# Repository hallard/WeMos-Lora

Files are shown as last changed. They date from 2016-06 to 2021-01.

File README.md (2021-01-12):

# ESP8266 WeMos Shield for HopeRF RFM95 RFM96 RFM98 Lora Modules

This shield is used to hold HopeRF [Lora module][4] Software with WeMos ESP8266 boards it has just few minimal features. 
- I2C Pullups placement
- Classic I2C 128x64 OLED connector
- Placement for RFM95/96/98 Lora module
- Placement for choosing single Wire, SMA or u-FL Antenna type 
- 2 x WS2812B Type LED for visual indication
- Custom switch on GPIO2
- Added footprint for Microchip 24AA02E64 64 bits serial number (v1.1+) 
- Added Solder PAD jumper to be able to connect GPIO16 to Reset to enable deep sleep (V1.2+)

You can find more information on WeMos D1 mini boards ([mini][1], [mini pro][7], [mini lite][8]), it's really well documented.
I now use WeMos boards instead of NodeMCU's one because they're just smaller, features remains the same, but I also suspect WeMos regulator far better quality than the one used on NodeMCU that are just fake of originals AMS117 3V3.

Boards arrived, I tested them, works fine with forked version of [single Channel LoRaWAN Gateway][5] but you can use any program that is compatible with RFM95 Lora module according it to real pinout.

## Detailed Description

Look at the schematics for more informations.

SPI connexion is classic (MOSI/MISO/CLK), 

**New v1.3** Solder pad on bottom layer to be able to switch 3V3 and GND Pin. It's configured as old version mapping by default (silkscreen is correct). 

Since V1.2, chip Select is still connected with GPIO16 by default but solder pad on bottom of the board allow you to connect GPIO16 to RESET for Deep Sleep. In this case: 

- add and solder R3 Pulldown (100K) to make RFM95 SPI device always selected
- on bottom solder pad cut trace between GPIO19 and SEL 
- on bottom solder join GPIO16 and RST with solder

Other pins that may need be adapted into code (for example if you use TTN network gateway code) according to the following pinout

Please not that to avoid 3 GPIOs for DIO0,DIO1,DIO2 Interrupt, these 3 are OR'ed with 3 diodes, respectively named D2,D3 and D4. This permit to use only one IRQ pin (here GPIO15). This is only possible because on IRQ routine the RFM9x IRQ register is read and then software knows which one has been triggered.
You can see more details ont this dedicated LMIC [Pull Request][6]

```
   WeMos D1          RFM9x Module
  GPIO12 (D6) <----> MISO
  GPIO13 (D7) <----> MOSI
  GPIO14 (D5) <----> CLK
  GPIO15 (D8) <----> DIO0/D2 OR DIO1/D3 OR DIO2/D4
  GPIO16 (D0) <----> SEL Chip Select (depending on bottom solder PAD position)

   WeMos D1         Shield Feature
  GPIO5  (D1) <----> I2C SCL
  GPIO4  (D2) <----> I2C SDA
  GPIO0  (D3) <----> WS2812 LEDS
  GPIO2  (D4) <----> Push Button
  GPIO16 (D0) <----> RESET (depending on bottom solder PAD position)
```

## Schematic  

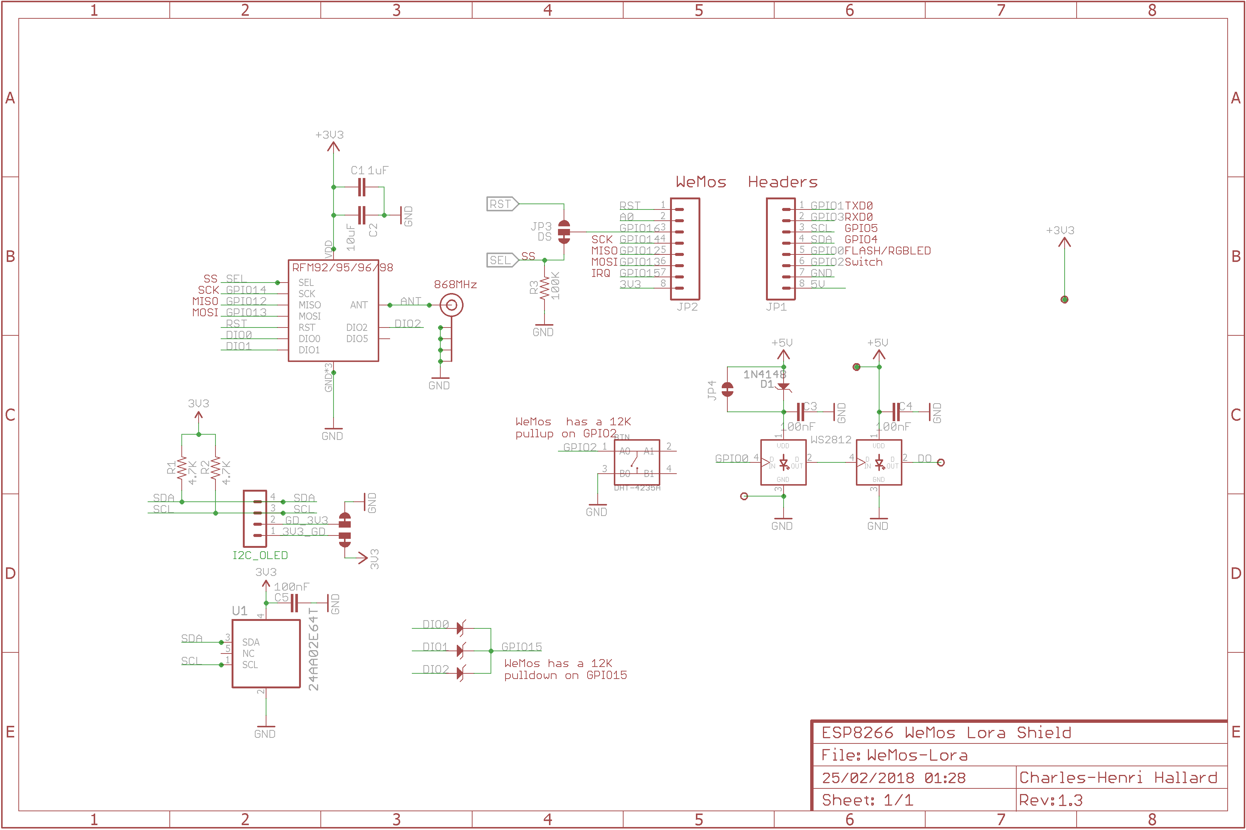
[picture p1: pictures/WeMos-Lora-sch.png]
schematic
  

## Bill Of Material

Nothing fancy, all components are 0805 and/or PTH and can be ordered almost anywhere (digikey, mouser, radiospare, ...). 
use only what you need dependings on what you want to do. You can find lot of components on ebay or aliexpress, but since vendors are often ephemere, I put for reference the BOM on well known providers.

Here is the [octopart BOM](https://octopart.com/bom-tool/SJPhS5Am)

## Firmware  

[firmware](https://github.com/hallard/WeMos-Lora/tree/master/firmware)  

## Boards  

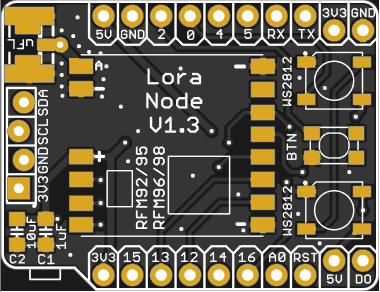
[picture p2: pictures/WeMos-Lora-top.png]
&nbsp;
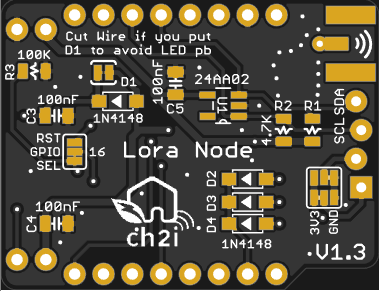
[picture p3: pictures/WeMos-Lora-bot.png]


~~You can order the PCB of this board at [PCBs.io][3] if you do so, PCBs.io give me discount that allow me to buy some new created boards.~~
   
Looks like PCBs.io is gone, I do not have any rewards from PCBs.io since August 2020 and my free order placed after are still not received, so my guess they are not on business anymore.

So you can order the board on [oshpark](https://oshpark.com/shared_projects/E9P1U0Ae). It's a pitty after several discuss with OSHPark that I can't have any rewards for each people ordering my boards, this would allow me to order free PCB for shared projects and create new ones. For information my shared boards generated a total of **$285 162.00** orders at PCBs.io in 4 years, not bad at all :-)

Hoping one day OSHparks will thanks me giving them this market. 

## Assembled boards (V1.0)

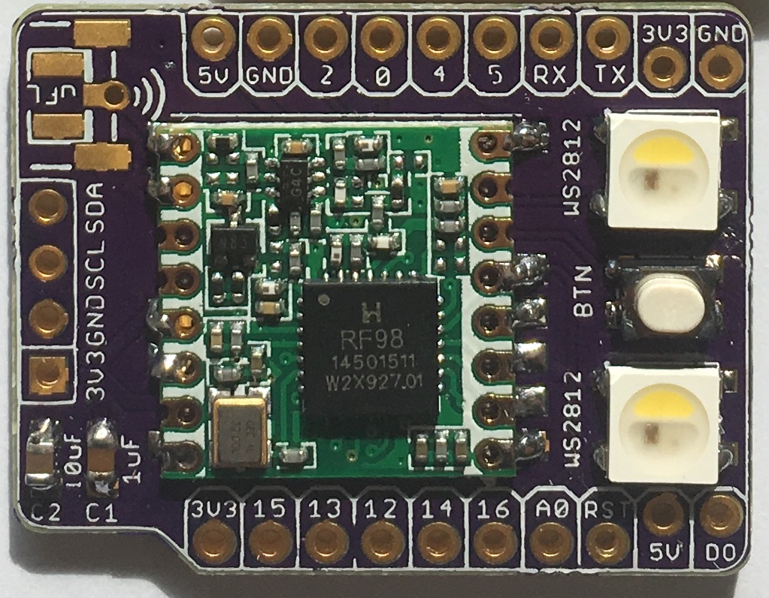
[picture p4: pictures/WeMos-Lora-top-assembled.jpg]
    
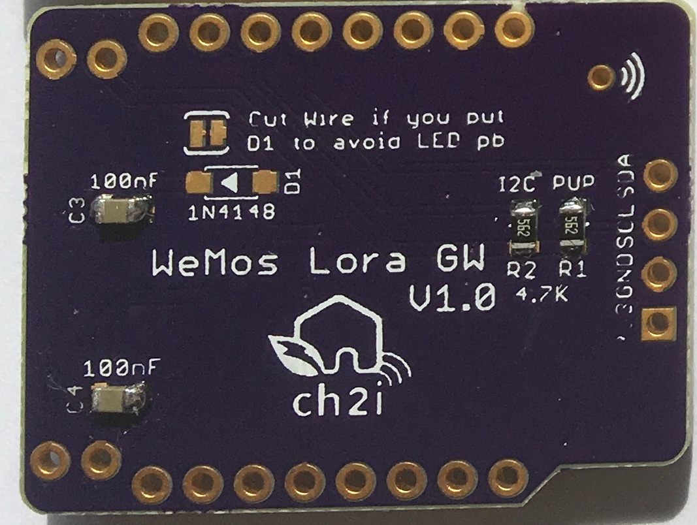
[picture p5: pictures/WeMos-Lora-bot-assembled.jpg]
    

## License

   

This work is licensed under a [Creative Commons Attribution-NonCommercial 4.0 International License](http://creativecommons.org/licenses/by-nc/4.0/)    
If you want to do commercial stuff with this project, please contact [CH2i company](https://www.ch2i.eu/en#support) so we can organize an simple agreement.

# Misc

See news and other projects on my [blog][2] 
 
[1]: https://wiki.wemos.cc/products:d1:d1_mini
[2]: https://hallard.me
[3]: https://PCBs.io/share/4Q1Z4 
[4]: http://www.hoperf.com/rf_transceiver/lora/
[5]: https://github.com/hallard/ESP-1ch-Gateway/
[6]: https://github.com/matthijskooijman/arduino-lmic/pull/34
[7]: https://wiki.wemos.cc/products:d1:d1_mini_pro
[8]: https://wiki.wemos.cc/products:d1:d1_mini_lite

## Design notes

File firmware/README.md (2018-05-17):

Lora Firmware for ESP8266 or ESP32 with RFM95
=============================================

You can use this [firmware fork](https://github.com/SensorsIot/ESP-1ch-Gateway) for example as Single Chanel Gateway

Dependencies
------------
- Arduino [ESP8266][6]
- @me-no-dev [ESPAsyncWebServer][4] library
- @me-no-dev [ESPAsyncTCP][5] library 
- [nodejs][7] for web pages development test 

Misc
----
See news and other projects on my [blog][2] 
 
[1]: http://www.wemos.cc/
[2]: https://hallard.me
[3]: http://terminal.jcubic.pl/
[4]: https://github.com/me-no-dev/ESPAsyncWebServer
[5]: https://github.com/me-no-dev/ESPAsyncTCP
[6]: https://github.com/esp8266/Arduino/blob/master/README.md
[7]: https://nodejs.org/
[8]: https://github.com/hallard/WeMos-RN2483/blob/master/README.md
[9]: http://cdn.rawgit.com/hallard/WebSocketToSerial/master/webdev/index.htm
[10]: https://github.com/hallard/WebSocketToSerial/tree/master/webdev
[11]: https://github.com/hallard/WebSocketToSerial/blob/master/webdev/create_spiffs.js
[12]: https://github.com/hallard/WebSocketToSerial/blob/master/webdev/web_server.js
[13]: https://github.com/hallard/WebSocketToSerial/tree/master/data

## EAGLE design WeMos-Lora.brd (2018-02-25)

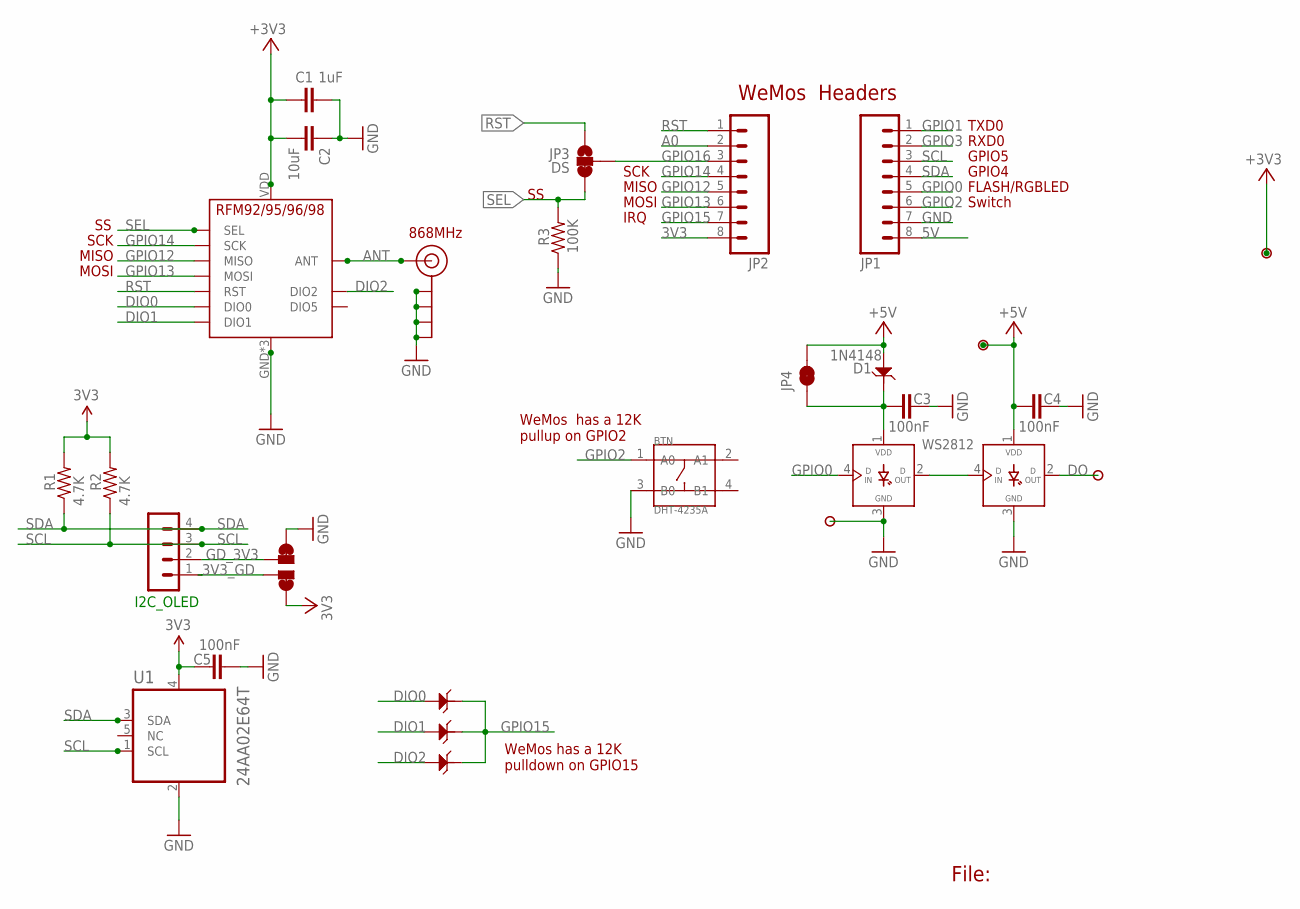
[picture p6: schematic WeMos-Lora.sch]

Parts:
BTN: DHT-4235A; SW4-SMD-4.2X3.2X2.5MM
C1: 1uF; 0805-CAP-LARGEPADS
C2: 10uF; 0805-CAP-LARGEPADS
C3, C4, C5: 100nF; 0805-CAP
D1, D2, D3, D4: 1N4148; SOD123-2.7X1.6
I2C_OLED: CON_HEADER_1X04'LOCK'; 1X04_LOCK
J$2: ANTENNATINY; SMA_UFL_PAD_TINY
JP1, JP2: M08NO_SILK_FEMALE_PTH; 1X08_NO_SILK
JP3: DS; PAD-JUMPER-3-2OF3_NC_BY_TRACE_YES_SILK_FULL_BOX
JP4: JUMPER-PAD-2-NC_BY_TRACE; PAD-JUMPER-2-NC_BY_TRACE_YES_SILK
P1, P2, P3, P4: PADNORMAL; PAD
R1, R2: 4.7K; 0805-RES
R3: 100K; 0805-RES
U1: 24AA02E64T; SOT95P270X145-5N
U$2: PAD-JUMPER-SWAPSWAP; PAD-JUMPER-SWAP
U$5: RFM95
WS1, WS2812: WS2812B

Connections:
3V3: C1.2, C2.2, C5.1, JP2.8, P4.1, R1.2, R2.2, U1.4 (VCC), U$2.4, U$2.44 (4), U$5.VDD (VCC)
3V3_GD: I2C_OLED.1, U$2.3
5V: C4.1, D1.1, JP1.8, JP4.2, P1.1, WS1.1 (VDD)
A0: JP2.2
ANT: J$2.ANT1 (SIGNAL), J$2.ANT2 (SIGNAL), J$2.ANT3 (SIGNAL), U$5.ANT
DIO0: D2.1, U$5.DIO0
DIO1: D3.1, U$5.DIO1
DIO2: D4.1, U$5.DIO2
DO: P2.1, WS1.2 (DOUT)
GD_3V3: I2C_OLED.2, U$2.2
GND: BTN.3 (B0), C1.1, C2.1, C3.2, C4.2, C5.2, J$2.GND1 (GND), J$2.GND2 (GND), J$2.GND3 (GND), J$2.GND4 (GND), JP1.7, P3.1, R3.1, U1.2 (VSS), U$2.1, U$2.11 (1), U$5.GND, U$5.GND1 (GND), U$5.GND2 (GND), WS1.3 (GND), WS2812.3 (GND)
GPIO0: JP1.5, WS2812.4 (DIN)
GPIO1: JP1.1
GPIO2: BTN.1 (A0), JP1.6
GPIO3: JP1.2
GPIO12: JP2.5, U$5.MISO
GPIO13: JP2.6, U$5.MOSI
GPIO14: JP2.4, U$5.SCK
GPIO15: D2.2, D3.2, D4.2, JP2.7
GPIO16: JP2.3, JP3.2
unnamed: WS1.4 (DIN), WS2812.2 (DOUT)
RST: JP2.1, JP3.1, U$5.RST
SCL: I2C_OLED.3, JP1.3, R2.1, U1.1 (SCL)
SDA: I2C_OLED.4, JP1.4, R1.1, U1.3 (SDA)
SEL: JP3.3, R3.2, U$5.NSS (SEL)
VLED: C3.1, D1.2, JP4.1, WS2812.1 (VDD)

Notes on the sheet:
File:
FLASH/RGBLED
MISO
GPIO4
GPIO5
RXD0
TXD0
MOSI
SCK
IRQ
WeMos Headers
868MHz
Switch
WeMos has a 12K pullup on GPIO2
WeMos has a 12K pulldown on GPIO15

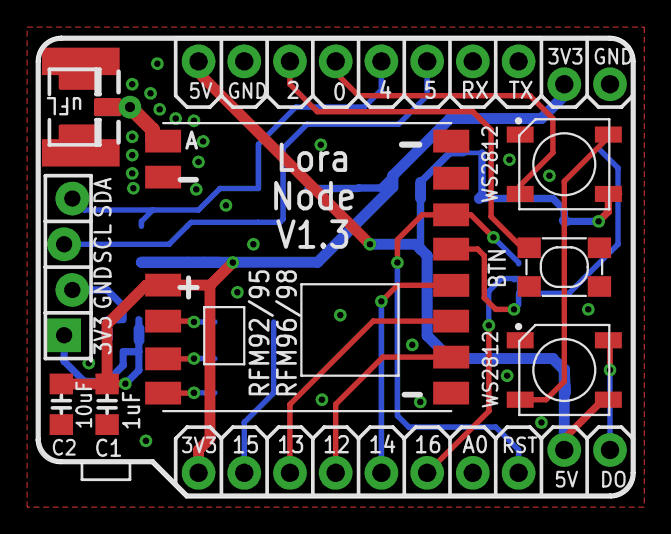
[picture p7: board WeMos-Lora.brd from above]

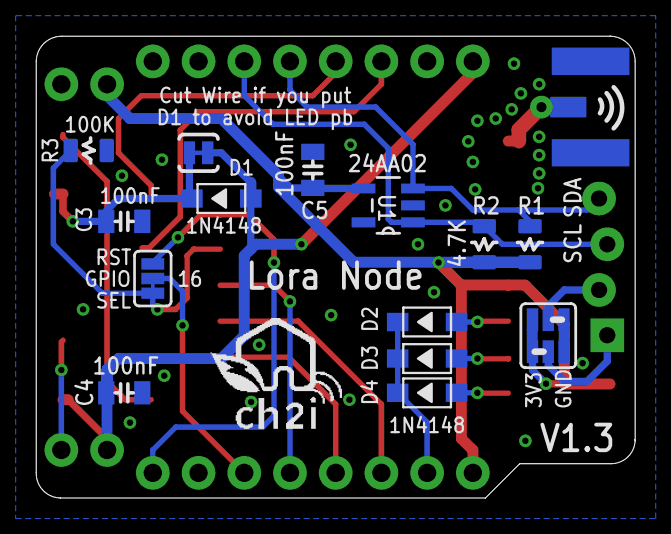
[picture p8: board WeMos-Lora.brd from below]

Board: 2 copper layers, 33.3 x 25.7 mm, 29 parts (15 on the bottom side), 23 nets.

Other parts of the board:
U$4: LOGO_CH2I_75MM

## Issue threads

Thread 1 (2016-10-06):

Replace 24AA02E64

Vitaliy86, 2016-10-06:
I cannot find 24AA02E64 for buy, can i replace it?

hallard, 2016-10-17:
@Vitaliy86
If you don't have the according code in your firmware, you can skip this chip, it's just in case you need specific unique ID on board and don't want to put in in the code.
you can find it on lot of electronic component provider such as
-  [digikey](http://www.digikey.com/product-detail/en/microchip-technology/24AA02E64-I-SN/24AA02E64-I-SN-ND/3908643)
- [mouser](http://www.mouser.fr/ProductDetail/Microchip-Technology/24AA02E64-I-SN)
- [TME](http://www.tme.eu/gb/details/24aa02e64-i_sn/serial-eeprom-memories-integ-circ/microchip-technology/#)

Closed 2016-10-22.

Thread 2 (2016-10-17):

SSD1306 Header Alignment

tkerby, 2016-10-17:
Hi

In the 1.1 version the pins for the display on the board edge are out of alignment. The png image you have of the board in the repository also reflects this.

Thanks

Tim

hallard, 2016-10-17:
@tkerby
The pin for the display are not aligned to be able to plug display without soldering it for testing or to let the header connector in place when soldering it, it's called "header lock" and used very often by sparkfun and other ;-)

Closed 2016-10-17.

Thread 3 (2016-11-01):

Unable to use deep sleep

JaapBraam, 2016-11-01:
I am running a LMIC implementation using this shield. This works fine, but the choice of using GPIO16 for SS breaks the possibility to use the timed deep sleep feature of the ESP8266. In order to make timed deep sleep work you have to connect GPIO16 to the ESP's RST pin. When using this shield, the board won't start up properly when connecting GPIO16 to RST. Maybe, in the next version, the GPIO16 pin can be used for an optional feature so there will be a way to use timed deep sleep.
Especially for battery powered LoraWan nodes a lot of power can be preserved by using deep sleep.

tkerby, 2016-11-24:
I've come across exactly the same issue here. I'd be tempted to wire the button to D0/GPIO16 instead. With a solder bridge option, you can either have deep sleep or a button input. If you select deep sleep then the button becomes an external reset that should cause the deep sleep to end early.

The other option here with the existing boards would be an external watchdog timer IC. The ESP would go into deep sleep then the watchdog would wake it up some time later.  To save pins, the SS line would suffice as a watchdog reset - ie any radio activity keeps the watchdog odd until deep sleep is issued

kragupat, 2016-12-02:
@JaapBraam  @tkerby
Which LMIC stack are you guys running with this board, I havent had much luck with either of the 2 below
https://github.com/hallard/arduino-lmic
https://github.com/matthijskooijman/arduino-lmic

any help is appreciated.

TheNitek, 2017-04-05:
I just create a fork ( https://github.com/TheNitek/WeMos-Lora ) which removes the LEDs and the button and also frees GPIO16. I just order my board, so I'm not sure yet everything still works, but maybe you want to give it a shot.

hallard, 2017-08-03:
Just released V1.2, if you want to try deep sleep, new PCB revision allow it ;-)

Closed 2017-08-03.

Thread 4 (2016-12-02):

Does 1.1 version work?

kragupat, 2016-12-02:
Hi ,
I recently ordered the board from pcbs.io  but so far haven't been able to get it working.
Tried it with your LMIC fork version both with and with out the diodes.
Has any one been able to successfully run it with 1.1 version boards.
Wemos keeps crashing right after serial.begin.
Also with the sheild attached I cant upload updated skeptch any more from arduino IDE, works ok if I take out the shield.

Thanks

hallard, 2018-02-25:
Did you solved your problem?
Version 1.2 works fine. I think I've got old V1.1 working version somewhere.

Closed 2018-02-25.

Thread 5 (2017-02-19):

DIO 1/2/3 and Diode 1n4148 - on schematics you have 3 diodes and on assebled picture only one

Netoperz, 2017-02-19:
As in title, the design and assembled dev pictures are different, could you tel me why, and if i want to connect the RFM95 module i should use 3 diodes as i understand, according to the schematics.

SensorsIot, 2017-04-20:
Same question for me. I had to remove the diode to DIO2, because it was always high and the gateway did not work. I also do not understand the role of D1. Is it necessary?
And in my case, the WiFi Neopixel shines red, even if the Gateway works properly.

hallard, 2017-08-03:
Guys
D1 is to lower power of WS2812B to 4.3V like this DI line in drived with 3.3V works, but it's not mandatory, new leds can be drived with 3.3V input when powered at 5V, you just need to try in fact.

To be full LMIC compliant (in term of node) I or'ed DIO0/DIO1/DIO2 with D2/D3/D4 on V1.1 version. May me for GW as said @SensorsIot we need to remove it depending on Server code (management of DIO)

Closed 2017-08-03.

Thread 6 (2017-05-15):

Please create shield for NiceRF Lora1276 with sensitivity up to -139 dBm

JosefJezek, 2017-05-15:
- https://www.aliexpress.com/item/2pcs-4km-range-Lora-TM100mW-SX1276-SPI-interface-Sensitivity-139-dBm-433MHz-LoRa1276-rf-long-distance/2015211844.html
- http://www.nicerf.com/product_146_136.html

JosefJezek, 2017-05-16:
RFM95W has sensitivity	-123dBm :-/

https://www.digikey.co.nz/product-detail/en/rf-solutions/RFM95W-868S2/RFM95W-868S2-ND/5051755

JosefJezek, 2017-05-16:
RN2483 has output power only 14 dBm

@hallard FYI

hallard, 2017-06-08:
@JosefJezek yes it could be cool but I'm pretty short in time for now and the footprint for this device does not exist for my PCB software Eagle CAD.
If you find an eagle library for it I can take some time to create it.

Closed 2017-08-03.

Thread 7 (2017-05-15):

Multiplexing made easier

platenspeler, 2017-05-15:
Hi,

I have been implementing the dio0,dio1,dio2 pin multiplexing in my single channel gateway using your excellent PCB.

When doing the same in regular LoRa node using your code I just wondered why you do not use the lmic_pin list. If dio[0]==dio[1] one would assume that you are multplexing the pins for a ESP8266 which will make the code really simple.

Maarten

PS. Something like

> static void hal_io_check() {
    uint8_t i;
  // If two DIO pins are equal, we assume pin multiplexing
  if (lmic_pins.dio[0]==lmic_pins.dio[1])
  {
	// Check IRQ flags in radio module
	if ( radio_has_irq() )
		radio_irq_handler(0);
  }
  //
  else {
    for (i = 0; i < NUM_DIO; ++i) {
        if (lmic_pins.dio[i] == LMIC_UNUSED_PIN)
            continue;

        if (dio_states[i] != digitalRead(lmic_pins.dio[i])) {
            dio_states[i] = !dio_states[i];
            if (dio_states[i])
                radio_irq_handler(i);
        }
    }
  }
}

hallard, 2017-05-23:
@platenspeler
Not sure to understand, you are multiplexing DIO pins with diode, and all DIO are so going to only one IO correct ?
If so you just have to check only one pin (the others are set to LMIC_UNUSED_PIN) and the LMIC should works right out of the box without any code modification.

Another possibility is to not connect any GPIO pin and check IRQ register of RFM95 module, the fork to support this No DIO connexion is [here](https://github.com/hallard/arduino-lmic) and works fine on all my nodes ;-)

Closed 2017-08-03.

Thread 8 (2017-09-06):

lolin?

xor256, 2017-09-06:
meybe using https://www.banggood.com/Wemos-Lolin-ESP32-OLED-Module-For-Arduino-ESP32-OLED-WiFi-Bluetooth-Dual-ESP-32-ESP-32S-ESP8266-p-1148119.html
esp + oled

what You thing about cc1101
3 band

hallard, 2018-02-25:
Something like this maybe ? Sorry long time ago
https://github.com/hallard/LoLin32-Lora

Closed 2018-02-25.

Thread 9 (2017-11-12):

Can't find the right SMA connector to fiit this pcb

certeza, 2017-11-12:
The placement of the center pin seems unusual.
Where can I find the right SMA connector?

marssystems, 2017-11-12:
These SMA connectors work perfectly for me -

https://www.ebay.co.uk/itm/5pcs-End-Launch-PCB-Mount-Bulkhead-SMA-Female-RF-Coaxial-Connector-Straight-I6V4/282493230059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

certeza, 2017-11-12:
Thnx!

Closed 2018-02-25.

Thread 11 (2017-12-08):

Screen Print Error?

KevDuino, 2017-12-08:
Thanks for this great board.
I made some problems for myself following the screen print.  The board matches the circuit diagram with NSS connected to GPIO16.  The Detail Description is also clear.  I think RST and SEL are labelled incorrectly.

hallard, 2018-02-25:
Correct, fixed in V1.3, thanks for pointing out

Closed 2018-02-25.

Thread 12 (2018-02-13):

OLED module PINs

DooMMasteR, 2018-02-13:
The order seems a bit weird, 99% of the cheap modules have the pin in the order

```GND Vcc SCL SDA```

and not

```Vcc GND SCL SDA```

as on the your PCB

hallard, 2018-02-24:
You're right, but when I created the board 90% of OLED was in this order, after that we had OLED price going up then again down, and I saw they have switched the pin, don't know why they do that but was not a good idea ;-)
that's why on new boards I make you can revert vcc/gnd by solder pad, I need to update this one

hallard, 2018-02-25:
Fixed in V1.3

Closed 2018-02-25.

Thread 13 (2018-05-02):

Button on ebay

incyi, 2018-05-02:
Hi,

Can you help me to find the button on ebay ? I can't find it. I found this one:
https://www.ebay.com/itm/100pcs-3X6X2-5mm-Tactile-Push-Button-Switch-Tact-Switch-Micro-Switch-2Pin-SMD-S2/261995936109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

KevDuino, 2018-05-02:
I used:
 https://www.aliexpress.com/item/20PCS-LOT-SMD-3-4-2-0MM-touch-switch-button-switch-feet-of-copper-legs-3X4X2/32774579893.html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
Aliexpress, 20PCS/LOT SMD 3 * 4 * 2.0MM touch switch button switch feet of copper legs 3X4X2.0MM SMD 4P 3X4X2 4Pin, £0.74 including delivery.

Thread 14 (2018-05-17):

Bill of materials

jpmeijers, 2018-05-17:
Please add a list of components needed to populate this board. I was unaware that I needed 3 diodes to get it in a usable state. I am also still unsure which exact component the diodes should be. Are they 0805?

* Number (ex. D1, R3)
* Value (ex. 1N4148, 10K)
* Footprint/size (ex. 0805)
* A link to a source for the component

hallard, 2018-05-17:
@jpmeijers
As indicated in the readme, diodes are not mandatory is you use my LMIC fork.
If not, then you need to solder them. Since schematics and board files are in the repo I thought it was easy to find these informations about components. But I was wrong, sorry.

So here is the [octopart BOM](https://octopart.com/bom-tool/SJPhS5Am) file, I've updated to ReadMe to add this link

Thanks for pointing it out.

Closed 2018-05-17.

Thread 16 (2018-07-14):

OLED Pins misalignment

hotzenklotz, 2018-07-14:
In v1.3 the holes for the OLED pins are misaligned. The center hole seems flipped and does not align perfectly with the other two PINs. This makes it hard to just "plug and play" a standard breadboard-friendly OLED screen.

Is there any reason for this layout?

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

hallard, 2018-09-17:
It's for soldering connector, like that it fit in place when soldering.
BTW you can also just plug OLED onto, it will also stay in place with this format.

hotzenklotz, 2018-09-17:
@hallard Which connector did you use?

I was hoping to plug [my 4 pin display](https://www.aliexpress.com/item/0-91-Inch-128x32-IIC-I2C-Blue-OLED-LCD-Display-DIY-Module-SSD1306-Driver-IC-DC/32793415973.html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) directly into the PCB.

Closed 2018-09-17.

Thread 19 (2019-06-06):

Pullup resistors on I2C, why?

atrent, 2019-06-06:
Hi, is there a motive for R1 and R2 (pullup resistors for SDA and SCL)?
I'd like to use Wemos pins D1 and D2 for a SoftwareSerial...
Thanks

pfeerick, 2019-06-29:
Because [I<sup>2</sup>C needs pullups](https://learn.sparkfun.com/tutorials/i2c/i2c-at-the-hardware-level).

If you're not going to use I<sup>2</sup>C, don't put them on.

atrent, 2019-07-10:
thanks for the reply (and sorry for the delay in my follow up)

I actually have an old version of the shield (see photo) and I've checked now that R1, R2 and the 24AA... chip are NOT present, so the fact that I could not activate a SoftwareSerial on those pins is to be investigated more, my bad

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

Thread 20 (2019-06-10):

SMD component list

leocopter, 2019-06-10:
Hi, could you provide the SMD component list ( with dimensions) ?
Thanks.

pfeerick, 2019-06-29:
Um... under Bill of Materials on the front readme?
> all components are 0805 and/or PTH

and

> Here is the [octopart BOM](https://octopart.com/bom-tool/SJPhS5Am)

leocopter, 2019-06-29:
Thank you.
Do you think this 24AA
02 :
https://m.ebay.ca/orderDetails?itemId=271542332935&txnId=2161023119017
Is the right one ?

Regards,

Chris

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

pfeerick, 2019-06-29:
Yeah, [that one](https://www.ebay.ca/itm/EEPROM-SERIAL-2KB-SMD-SOT-23-5-Part-24AA02T-I-OT/271542332935) looks like it should be fine... it's the right part number, and it's the five legger S0T-23-5, not the 8 leg SOIC-8 package.

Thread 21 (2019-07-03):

DIO0 GPIO15 boot fail

NitroProp, 2019-07-03:
Hi, i have an issue, the gateway works perfectly fine but i have a small problem, i have the gpio15 pulled down to ground with a 10k resistor, but if i connect the 1n4148 diode for dio0 on gpio15 the esp12e will not boot. If i leave the diode disconnected, power up the board and only then connect the diode on gpio15 it works like a charm, any idea about the reason ?

Thanks a lot

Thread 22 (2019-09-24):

BOM missing antenna connector

remrat, 2019-09-24:
Any advice on the type of antenna connector to put on the PCB?  I noticed the BOM is missing that info.

I would love to use a SMA or u.fl type antenna, but don't know of a connector that fits that footprint on the PCB.

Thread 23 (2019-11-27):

Older Versions

peterl3233, 2019-11-27:
I appear to have a quantity of older "Lora Node Mini" boards for Wemos D1 mini.  I bought them about 2 years ago. They do not have a version number or CH21 logo but have the number WS2812 screened just under the RFM9x moduls pads. The layout and parts placement is identical to V1.3 sans the extra features.
So, Question is:  Is this indeed an early version of WeMos-Lora and is is usable?
Thanks much Peter

TheNitek, 2019-11-27:
Is it maybe the early version of my fork (https://github.com/TheNitek/WeMos-Lora/)? I reduced the original in size an called it mini and reduced it further later on and started to call it micro.
If so it will still work perfectly fine.

TheNitek, 2019-11-27:
Looks like this: https://s3.amazonaws.com/pcbsio/svgs/43aeafab5f987c7c728c912dfaa8ddd3aa04478626dfc0893355db2fd9175ac8/top.svg

peterl3233, 2019-11-28:
Hi Claus; Its slightly different than both examples that you cited. This one has the OLED connector pins.  I found my records and I bought them from PCBS.io. Bought in September 2017. Searching their website no longer finds this one.  Hopefully you can see the attached photo.

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

TheNitek, 2019-11-28:
That’s my forked version

peterl3233, 2019-11-28:
Thanks much.  I just bought some RFM95's to play LoRa ... Too much fun!

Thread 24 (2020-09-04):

BOM missing diodes

gvtienen, 2020-09-04:
Hello,
Your BOM (at https://octopart.com/bom-tool/MsqCYjTr) is missing the 3 diodes

gvtienen, 2020-09-06:
Sorry, I was looking into the mini-LoRa BOM file :(

gvtienen, 2020-09-06:
Sorry, I was looking into the mini-LoRa BOM file :(

gvtienen, 2020-09-06:
Sorry, I was looking into the mini-LoRa BOM file :(

gvtienen, 2020-09-06:
Sorry, I was looking into the mini-LoRa BOM file :(

gvtienen, 2020-09-06:
Sorry never mind, I was mixing the mini-LoRa with the WeMos-Lora

gvtienen, 2020-09-06:
Sorry never mind, I was mixing the mini-LoRa with the WeMos-Lora

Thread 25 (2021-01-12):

Ordering new pcbs for WeMos Lora RFM9x Gateway Shield

saysphilippe, 2021-01-12:
Hi, I have tried several times to order your board from PCBs.io - but it looks like they have issues there. Are your boards available somewhere else?

hallard, 2021-01-12:
To be honest I do not have any rewards from PCBs.io since August 2020 so my guess they are not on business anymore because got boards never received

So I added link so you can order the board on [oshpark](https://oshpark.com/shared_projects/E9P1U0Ae)

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

saysphilippe, 2021-01-12:
Great, thank you!

henkiejan1, 2021-01-14:
First of all i do not work for TTGO or Lilygo. But i read that TTGO also made pcb's with a minimum quantity of 1. S[ee this from their website.](https://0.rc.xiniu.com/g3/M00/16/67/CgAH513o4-mAIb7uAAHywAhSKd0113.jpg) Maybe a good idea to contact TTGO?

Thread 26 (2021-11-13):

Correct Pins?

eboston, 2021-11-13:
I know this project is old, but it seems the hardware should still be usable.  I am trying to make a LoRa transmitter using the LoRa library in the Arduino IDE.  I am converting code I was running on a Heltec ESP32 LoRa board.  I am trying to follow this (https://github.com/SensorsIot/LoRa-Point-to-Point) which uses this board.  I'm not sure if the board has been assembled correctly, but I think it has.  Both the leds and oled are working, but I know they are not part of the LoRa portion.

In the sample code, it uses this command to configure the pins:
`  LoRa.setPins(16, 17, 15); // set CS, reset, IRQ pin`
It compiles and runs, but the receiver I have is not seeing anything.  They are both on the same frequency and SF.

Any suggestions on what might not be right?

EDIT:  I am seeing it get a package every once in awhile, so I guess it is transmitting, but most of the packets aren't being received.

Closed 2021-11-15.

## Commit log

2016-07-07 Version V1.1
    - OLED Display connector has now lock pad
    - Antenna signal with via all around
    - ground plane set to 12min blocking to avoid short circuit with
    connectors in rarely cases
    - Added footprint for Microchip 24AA02E64 64 bits serial number
    [WeMos-Lora.brd, WeMos-Lora.sch]
2017-08-03 Bump to V1.2
    [WeMos-Lora.brd, WeMos-Lora.sch]
2018-02-25 Bump to v1.3
    [WeMos-Lora.brd, WeMos-Lora.sch]
2018-05-17 Added BOM
2026-04-29 Switch to CC BY-NC-SA 4.0 license, add LICENSE file

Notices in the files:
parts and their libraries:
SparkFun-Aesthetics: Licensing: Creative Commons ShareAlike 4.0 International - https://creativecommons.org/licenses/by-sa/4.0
